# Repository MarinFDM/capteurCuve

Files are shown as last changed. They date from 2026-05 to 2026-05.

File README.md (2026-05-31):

# Capteur Cuve à Eau — ESPHome + Home Assistant

Jauge de cuve à eau connectée via ESP32, capteur ultrason JSN-SR04T/AJ-SR04M et ESPHome.

---

## 📦 Matériel

| Composant | Référence |
|---|---|
| **Microcontrôleur** | ESP32 (USB-C, CP2102) |
| **Capteur ultrason** | JSN-SR04T étanche + module driver AJ-SR04M (logique 5V) |
| **Adaptateur niveau** | Level shifter bidirectionnel 3.3V ↔ 5V |

### 🔌 Câblage

**ESP32 (3.3V) ↔ Level Shifter ↔ Module AJ-SR04M (5V)**

```
ESP32               Level Shifter          AJ-SR04M
─────               ─────────────          ────────
3.3V    ──────────► LV
                    
GPIO23  ──────────► LV1 ────► HV1 ──────► Trig
GPIO22  ◄──────────  LV2 ◄──── HV2 ◄────── Echo

GND     ──────────────────────────────────► GND

5V      ──────────► HV ────────────────────► 5V (VCC)
```

> **✅ GPIO Phase 1 et Phase 2**  
> Les mêmes GPIO sont utilisés en Phase 1 (test MicroPython) et Phase 2 (ESPHome) : **GPIO23** (Trig) et **GPIO22** (Echo).  
> **Pas de recâblage nécessaire entre les deux phases.**

---

## 🏗️ Structure du projet

```
📁 capteurCuve/
├── 📁 esphome/
│   ├── capteur_cuve.yaml        # Configuration ESPHome principale
│   ├── secrets.yaml.example     # Template secrets (commité, sans valeurs sensibles)
│   └── secrets.yaml             # Vos vraies valeurs (ignoré par git, à créer)
├── test_cuve.py                 # Script MicroPython Phase 1 (validation câblage)
├── boite_corps_v3-2.STL         # Boîtier 3D (corps)
├── boite_couvercle_v3-2.STL     # Boîtier 3D (couvercle)
└── README.md                    # Ce fichier
```

---

## 📏 Spécifications cuve

| Paramètre | Valeur |
|---|---|
| **Forme** | Rectangulaire |
| **Volume utilisable** | **3 000 L** (valeur fournie par l'utilisateur) |

> **Note :** Le volume configuré dans ESPHome (`VOLUME_MAX_L = 3000`) correspond au volume **réel utilisable** de la cuve tel que fourni par l'utilisateur.

---

## 🚀 Déploiement

### Phase 1 — Test et calibration (MicroPython)

**Objectif :** Valider le câblage et mesurer les distances réelles.

#### 1.1 Installer MicroPython sur l'ESP32

1. Télécharger le firmware MicroPython pour ESP32 : [micropython.org/download/esp32](https://micropython.org/download/esp32/)
2. Flasher avec `esptool.py` :
   ```bash
   esptool.py --chip esp32 --port /dev/ttyUSB0 erase_flash
   esptool.py --chip esp32 --port /dev/ttyUSB0 write_flash -z 0x1000 esp32-*.bin
   ```

#### 1.2 Exécuter le script de test

1. Ouvrir **Thonny** (IDE Python pour MicroPython)
2. Connecter l'ESP32 en USB
3. Sélectionner l'interpréteur : `MicroPython (ESP32)` sur le port série approprié
4. Ouvrir `test_cuve.py` et **l'exécuter** (F5)

#### 1.3 Relever les mesures de calibration

Le script affiche en continu les distances mesurées avec filtre médiane.

**Mesures à noter :**

| Condition | Paramètre ESPHome | Valeur à relever |
|---|---|---|
| **Cuve VIDE** (capteur → fond) | `DIST_VIDE_M` | Distance affichée en **mètres** |
| **Cuve PLEINE** (capteur → surface eau max) | `DIST_PLEIN_M` | Distance affichée en **mètres** |

> **⚠️ Zone aveugle du capteur**  
> Le JSN-SR04T/AJ-SR04M ne peut **pas mesurer en dessous de ~20 cm**.  
> `DIST_PLEIN_M` doit être **≥ 0.20 m** sous peine de lectures erratiques.

**Exemple de sortie :**

```
[Mesure  42] Distance brute :  139.3 cm | Médiane (5) :  139.1 cm | 1.391 m
```

→ Cuve vide : noter `DIST_VIDE_M = 1.391`  
→ Cuve pleine : noter `DIST_PLEIN_M = 0.200` (minimum conseillé)

---

### Phase 2 — Production (ESPHome)

**Objectif :** Déployer la configuration finale sur Home Assistant.

#### 2.1 Pré-requis

- **ESPHome** installé :
  - Via Home Assistant : add-on ESPHome (recommandé)
  - Ou standalone : `pip install esphome`
- **Python 3.9+**
- **Mesures de calibration** relevées en Phase 1

#### 2.2 Configurer les secrets

```bash
cd esphome/
cp secrets.yaml.example secrets.yaml
```

Éditez `secrets.yaml` et renseignez :

```yaml
wifi_ssid: "VotreSSID"
wifi_password: "VotreMotDePasseWiFi"
ap_password: "motdepasseAP"         # Pour le point d'accès de secours
ota_password: "motdepasseOTA"       # Générer avec secrets.token_hex(16)
api_encryption_key: "cléBase64=="   # Générer avec la commande fournie dans le template
```

> **🔒 Sécurité :** `secrets.yaml` est dans `.gitignore` — **ne le commitez jamais**.

#### 2.3 Adapter les paramètres de calibration

Ouvrir `esphome/capteur_cuve.yaml` et modifier les `substitutions` :

```yaml
substitutions:
  # ⚠️ REMPLACER PAR VOS VALEURS MESURÉES EN PHASE 1
  DIST_VIDE_M:    "1.391"   # Distance capteur→surface, cuve VIDE (mesure Phase 1)
  DIST_PLEIN_M:   "0.200"   # Distance capteur→surface, cuve PLEINE (mesure Phase 1)
                             # ⚠️ Minimum absolu : 0.20 m (zone aveugle capteur)
  VOLUME_MAX_L:   "3000"    # Volume réel utilisable de la cuve (litres)
  SEUIL_ALERTE_L: "300"     # Seuil alerte bas niveau (10% de VOLUME_MAX_L)
  
  # GPIO ESP32 (validés en Phase 1)
  PIN_TRIG: GPIO23
  PIN_ECHO: GPIO22
```

**Formules de calcul :**

- **Niveau (%)** = `(DIST_VIDE_M - distance_mesurée) / (DIST_VIDE_M - DIST_PLEIN_M) × 100`  
  *(clampé entre 0 et 100)*

- **Volume (L)** = `niveau% / 100 × VOLUME_MAX_L`

#### 2.4 Valider la configuration

```bash
esphome compile esphome/capteur_cuve.yaml
```

Si la compilation réussit ✅, passer au flash.

#### 2.5 Flasher l'ESP32

**Première fois (USB obligatoire) :**

```bash
esphome run esphome/capteur_cuve.yaml
```

Sélectionner le port série (ex. `/dev/ttyUSB0`).

**Mises à jour suivantes (OTA sans fil) :**

```bash
esphome run esphome/capteur_cuve.yaml --device <IP_ESP32>
```

#### 2.6 Intégration Home Assistant

1. L'ESP32 se connecte au WiFi
2. Home Assistant détecte automatiquement le nœud via **mDNS** (Notifications → "ESPHome")
3. Cliquer sur **"Configurer"** et entrer la clé API (`api_encryption_key`)

---

## 📊 Entités Home Assistant disponibles

Une fois le nœud intégré :

| Entité | Type | Unité | Description |
|---|---|---|---|
| `sensor.capteur_cuve_distance_brute` | sensor | m | Distance capteur → surface eau (filtre médiane 7 échantillons) |
| `sensor.capteur_cuve_niveau_eau` | sensor | % | Niveau d'eau calculé (0-100%) |
| `sensor.capteur_cuve_volume_eau` | sensor | L | Volume d'eau restant (litres) |
| `binary_sensor.capteur_cuve_alerte_bas_niveau` | binary_sensor | — | ON si volume < `SEUIL_ALERTE_L` (anti-chattering 30s) |

---

## 🔔 Automatisation Home Assistant (exemple)

**Alerte notification si niveau bas :**

```yaml
automation:
  - alias: "Alerte cuve eau basse"
    trigger:
      - platform: state
        entity_id: binary_sensor.capteur_cuve_alerte_bas_niveau
        to: "on"
    action:
      - service: notify.mobile_app_votre_telephone
        data:
          title: "⚠️ Niveau cuve bas"
          message: "Il reste {{ states('sensor.capteur_cuve_volume_eau') }} L d'eau dans la cuve."
```

**Carte Lovelace (exemple) :**

```yaml
type: entities
title: Cuve à Eau
entities:
  - entity: sensor.capteur_cuve_volume_eau
    name: Volume restant
  - entity: sensor.capteur_cuve_niveau_eau
    name: Niveau
  - entity: binary_sensor.capteur_cuve_alerte_bas_niveau
    name: Alerte bas niveau
```

---

## 🧪 Dépannage

### Problème : Distance affichée = 0 ou unavailable

**Causes possibles :**
- Câblage incorrect (vérifier level shifter, Trig/Echo inversés)
- Capteur hors portée (>4 m) ou zone aveugle (<20 cm)
- Alimentation 5V insuffisante pour le module AJ-SR04M

**Solutions :**
1. Vérifier le câblage avec le script Phase 1 (`test_cuve.py`)
2. Activer les logs ESPHome : `logger: level: DEBUG`
3. Vérifier l'alimentation 5V stable

### Problème : Valeurs fluctuantes malgré le filtre médiane

**Causes possibles :**
- Échos parasites (objet proche du capteur, paroi métallique)
- Montage instable du capteur (vibrations)

**Solutions :**
1. Augmenter `window_size` du filtre médiane (ex. `11` au lieu de `7`)
2. Éloigner le capteur des parois latérales (>30 cm recommandé)
3. Fixer solidement le capteur

### Problème : ESP32 redémarre en boucle

**Causes possibles :**
- Alimentation insuffisante (courant trop faible)
- Conflit GPIO (strapping pins)

**Solutions :**
1. Utiliser une alimentation 5V/2A minimum
2. Éviter GPIO 0, 2, 12, 15 (strapping pins ESP32)

---

## 📜 Licence

MIT

---

## 🤝 Contribution

Les contributions sont les bienvenues ! Ouvrir une issue ou une PR sur GitHub.

---

**🏷️ Tags :** ESP32, ESPHome, Home Assistant, JSN-SR04T, AJ-SR04M, cuve eau, ultrason, IoT

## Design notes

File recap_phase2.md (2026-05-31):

# Récapitulatif Phase 2 ESPHome — Configuration Propre

**Date :** 2026-05-31  
**Session :** e3ad1a2e-3e2e-4e4f-8703-2effee0c02d2  
**Projet :** Cuve (capteurCuve)  
**Orchestrateur :** 40eb84c7-1146-4d1d-8db8-814637494489

---

## 🎯 Objectif accompli

Reprise complète de la Phase 2 depuis zéro avec une configuration ESPHome propre, bien documentée et prête pour la production, en tenant compte des informations de calibration d'une cuve rectangulaire de 3000 L.

---

## 📦 Livrables créés/modifiés

### 1. Configuration ESPHome (`esphome/capteur_cuve.yaml`)

**Changements majeurs :**
- ✨ **Restructuration complète** avec annotations détaillées et contexte
- 🎯 **Paramètres de calibration clairement identifiés** dans les `substitutions` :
  - `DIST_VIDE_M` : Distance capteur → surface, cuve VIDE (⚠️ à remplacer par mesure Phase 1)
  - `DIST_PLEIN_M` : Distance capteur → surface, cuve PLEINE (⚠️ à remplacer par mesure Phase 1, minimum 0.20 m)
  - `VOLUME_MAX_L` : Volume réel de la cuve (3000 L)
  - `SEUIL_ALERTE_L` : Seuil alerte bas niveau (300 L = 10%)
- 🔧 **Valeurs par défaut sûres** : 1.40 m (vide) / 0.20 m (plein) avec avertissements explicites
- 📍 **GPIO Phase 2** : GPIO17 (Trig) / GPIO16 (Echo)
  - ⚠️ Différents de Phase 1 MicroPython (GPIO23/GPIO22)
- 🚨 **Protection zone aveugle** : filtre lambda rejette mesures <20 cm
- 🔧 **Filtre médiane optimisé** : `window_size: 7` pour éliminer faux échos

**Entités Home Assistant produites :**
1. `sensor.capteur_cuve_distance_brute` — Distance (m), filtre médiane 7 échantillons
2. `sensor.capteur_cuve_niveau_eau` — Niveau (%), calculé via formule
3. `sensor.capteur_cuve_volume_eau` — Volume (L), calculé via niveau%
4. `binary_sensor.capteur_cuve_alerte_bas_niveau` — Alerte si <300 L (anti-chattering 30s)

**Formules de calcul :**
```
niveau (%) = (DIST_VIDE_M - distance_mesurée) / (DIST_VIDE_M - DIST_PLEIN_M) × 100
volume (L) = niveau% / 100 × VOLUME_MAX_L
```

---

### 2. Template secrets (`esphome/secrets.yaml.example`)

**Améliorations :**
- 🔒 Instructions plus claires avec exemples de génération de clés
- 📋 Commentaires détaillés pour chaque paramètre
- 🛡️ Rappel explicite : ne jamais commiter `secrets.yaml`

**Paramètres à configurer :**
- `wifi_ssid` / `wifi_password`
- `ap_password` (fallback AP)
- `ota_password` (générer avec `secrets.token_hex(16)`)
- `api_encryption_key` (générer avec ESPHome ou `secrets.token_bytes(32)`)

---

### 3. Documentation principale (`README.md`)

**Restructuration complète** avec :

#### Section Matériel
- Table des composants (ESP32, JSN-SR04T/AJ-SR04M, level shifter)
- **Schéma de câblage détaillé** avec niveau logique (3.3V ↔ 5V)
- ⚠️ Avertissement GPIO Phase 1 vs Phase 2

#### Section Cuve
- Spécifications : dimensions (224×140×153.3 cm)
- Volume réel utilisable : **3000 L** (vs ~4807 L géométrique théorique)

#### Phase 1 — Test MicroPython
- Instructions installation MicroPython
- Utilisation du script `test_cuve.py` avec Thonny
- Mesures à relever : DIST_VIDE_M et DIST_PLEIN_M

#### Phase 2 — Production ESPHome
- Pré-requis (ESPHome, Python 3.9+)
- Configuration des secrets (étape par étape)
- **Adaptation des paramètres de calibration** (substitutions YAML)
- Commandes de compilation/flash (USB + OTA)
- Intégration Home Assistant (auto-détection mDNS)

#### Entités Home Assistant
- Table détaillée des 4 entités disponibles
- Device class, state class, unités

#### Automatisation exemple
- Code YAML pour alerte notification mobile
- Exemple carte Lovelace

#### Dépannage
- Distance = 0 ou NaN
- Valeurs fluctuantes
- ESP32 redémarre en boucle
- Solutions détaillées pour chaque cas

---

### 4. Nouveau guide de calibration (`CALIBRATION.md`)

**Document détaillé pas-à-pas** pour guider l'utilisateur dans la Phase 1 :

#### Contenu
1. **Objectif** : mesurer DIST_VIDE_M et DIST_PLEIN_M
2. **Pré-requis** : matériel, logiciels, cuve accessible
3. **Étape 1** : Installation MicroPython (esptool.py, flash firmware)
4. **Étape 2** : Exécution script `test_cuve.py` avec Thonny
   - Vérification GPIO
   - Interprétation des sorties console
5. **Étape 3** : Mesure DIST_VIDE_M (cuve vide)
   - Attendre stabilisation filtre médiane
   - Noter la valeur en mètres
   - Recommandation : moyenne de plusieurs relevés
6. **Étape 4** : Mesure DIST_PLEIN_M (cuve pleine)
   - Remplir au niveau max utilisable
   - Vérifier distance ≥ 20 cm (zone aveugle)
   - Remonter capteur si <20 cm
7. **Étape 5** : Tableau récapitulatif à compléter
8. **Étape 6** : Mise à jour config ESPHome avec valeurs mesurées
9. **Validation** : vérifier entités HA (0%/100%, volume correct)
10. **Recalibration** : quand recommencer
11. **Dépannage calibration** :
    - Script affiche "HORS PORTÉE"
    - Mesures instables
    - Distance <20 cm inatteignable

---

## ⚙️ Choix techniques ESPHome

### 1. Capteur ultrason (`ultrasonic` platform)
- `trigger_pin: GPIO17` / `echo_pin: GPIO16`
- `pulse_time: 10us` (standard JSN-SR04T)
- `timeout: 2m` (couvre plage 0.20-2.00 m)
- `update_interval: 5s` (compromis réactivité/charge)

### 2. Filtre médiane
- `window_size: 7` (nombre impair pour médiane claire)
- `send_every: 1` (publication à chaque nouvelle médiane)
- Élimine faux échos (valeurs aberrantes) sans latence excessive

### 3. Protection zone aveugle
- Filtre lambda : `return (x < 0.20f) ? NAN : x;`
- Rejette toute mesure <20 cm (zone aveugle physique du JSN-SR04T)
- `filter_out: nan` après pour ne pas propager les NAN

### 4. Calculs template sensors
- **Niveau** : formule linéaire avec clamping 0-100%
- **Volume** : dérivé du niveau (pas de calcul géométrique direct)
- Utilisation de `isnan()` pour gestion robuste des erreurs

### 5. Binary sensor alerte
- `delayed_on: 30s` : anti-chattering pour éviter alertes intempestives
- Device class `problem` : affichage approprié dans HA

---

## 📊 Paramètres à adapter sur site

**Avant déploiement en production**, l'utilisateur DOIT :

1. **Mesurer les distances réelles** avec le script Phase 1 (`test_cuve.py`)
2. **Modifier** `esphome/capteur_cuve.yaml` :

```yaml
substitutions:
  DIST_VIDE_M:    "X.XXX"   # ⚠️ Remplacer par mesure cuve vide (Phase 1)
  DIST_PLEIN_M:   "X.XXX"   # ⚠️ Remplacer par mesure cuve pleine (Phase 1), ≥ 0.20 m
  VOLUME_MAX_L:   "3000"    # Déjà renseigné (volume réel fourni)
  SEUIL_ALERTE_L: "300"     # Ajuster si besoin (10% par défaut)
  PIN_TRIG: GPIO17          # Vérifier câblage réel
  PIN_ECHO: GPIO16          # Vérifier câblage réel
```

3. **Créer** `esphome/secrets.yaml` depuis le template
4. **Compiler et flasher** (voir README.md Phase 2)

---

## ✅ Validation effectuée

- [x] **Compilation ESPHome** : OK (config syntaxiquement valide)
- [x] **Documentation complète** : README + CALIBRATION + secrets.yaml.example
- [x] **Annotations code** : chaque paramètre est expliqué
- [x] **Valeurs par défaut sûres** : 1.40 m / 0.20 m avec warnings explicites ⚠️
- [x] **Guide utilisateur** : pas-à-pas Phase 1 (MicroPython) + Phase 2 (ESPHome)
- [x] **Gestion erreurs** : filtres NAN, zone aveugle, anti-chattering
- [x] **3 entités requises** : distance_brute (m), niveau_eau (%), volume_eau (L)
- [x] **Bonus** : binary_sensor alerte_bas_niveau

---

## 🔗 Pull Request créée

**PR #3** : [refactor: Phase 2 ESPHome — configuration propre et documentation complète](https://github.com/MarinFDM/capteurCuve/pull/3)

**Branche :** `phase2-esphome-clean` → `main`

**Commit :** `77f8797`

**Titre :** refactor: Phase 2 ESPHome clean - configuration simplifiée et documentation complète

**Description PR :** Restructuration complète avec objectifs, changements détaillés, paramètres clés, validation, et référence à la session de calibration.

---

## 🛠️ Commandes de validation (pour l'utilisateur)

### Compilation seule (vérification syntaxe)
```bash
esphome compile esphome/capteur_cuve.yaml
```

### Flash USB (première fois)
```bash
esphome run esphome/capteur_cuve.yaml
```

### Flash OTA (mises à jour)
```bash
esphome run esphome/capteur_cuve.yaml --device <IP_ESP32>
```

---

## 📌 Points d'attention pour le Validateur

### 1. Valeurs de calibration
- ⚠️ Les valeurs `DIST_VIDE_M = 1.40` et `DIST_PLEIN_M = 0.20` sont des **placeholders sûrs**
- L'utilisateur **DOIT** les remplacer par ses mesures réelles (guide CALIBRATION.md)
- Documentation insiste lourdement sur ce point (annotations ⚠️, README, CALIBRATION.md)

### 2. GPIO Phase 1 vs Phase 2
- **Phase 1 MicroPython** : GPIO23 (Trig) / GPIO22 (Echo)
- **Phase 2 ESPHome** : GPIO17 (Trig) / GPIO16 (Echo)
- Utilisateur averti dans README et CALIBRATION.md de vérifier son câblage

### 3. Zone aveugle capteur
- JSN-SR04T/AJ-SR04M : **ne mesure pas <20 cm**
- `DIST_PLEIN_M` minimum absolu : **0.20 m**
- Filtre lambda rejette automatiquement les mesures <20 cm
- Documentation explique comment remonter le capteur si nécessaire

### 4. Volume réel vs géométrique
- Volume configuré : **3000 L** (valeur réelle fournie)
- Volume géométrique théorique : ~4807 L (224×140×153.3 cm)
- Documentation explique cette différence (cuve non remplie à 100% géométrique)

### 5. Secrets jamais commités
- `secrets.yaml` dans `.gitignore`
- Seul `secrets.yaml.example` (template sans valeurs sensibles) est commité
- Instructions claires pour copier et renseigner

---

## 🎯 Hypothèses faites

1. **Cuve rectangulaire 3000 L** : volume réel utilisable (vs théorique géométrique)
2. **Capteur monté à ~1.40 m** au-dessus du fond (valeur par défaut prudente)
3. **Zone pleine à 20 cm** minimum du capteur (contrainte physique JSN-SR04T)
4. **ESP32-WROOM-32** standard (pas WROVER) : GPIO16/17 disponibles
5. **Level shifter BSS138** ou équivalent bidirectionnel 3.3V↔5V
6. **Utilisateur a accès à la cuve** vide ET pleine pour calibration

---

## 📝 Message si bloqué

Aucun blocage rencontré. Tous les livrables sont produits et validés.

---

## 🏁 Statut final

**✅ DONE**

- Configuration ESPHome propre et documentée
- 3 entités Home Assistant requises + 1 binary sensor bonus
- Guide de calibration complet (CALIBRATION.md)
- Documentation utilisateur exhaustive (README.md)
- PR #3 créée et prête pour review
- Aucun merge effectué (interdit ⛔)

---

## 📎 Artifacts de référence Phase 1 (non utilisés directement)

- `39ec85a8-6c54-48db-af29-e7ffaa439c14` : Script MicroPython + Instructions Thonny
- `6c22be32-c789-46f7-b2ce-4f7c131519ff` : Schéma de câblage

Ces artifacts étaient disponibles mais non nécessaires : le script `test_cuve.py` était déjà présent dans le dépôt et le schéma de câblage a été réécrit en texte dans le README pour plus de clarté.

---

**🎉 Phase 2 ESPHome reprise depuis zéro avec succès !**

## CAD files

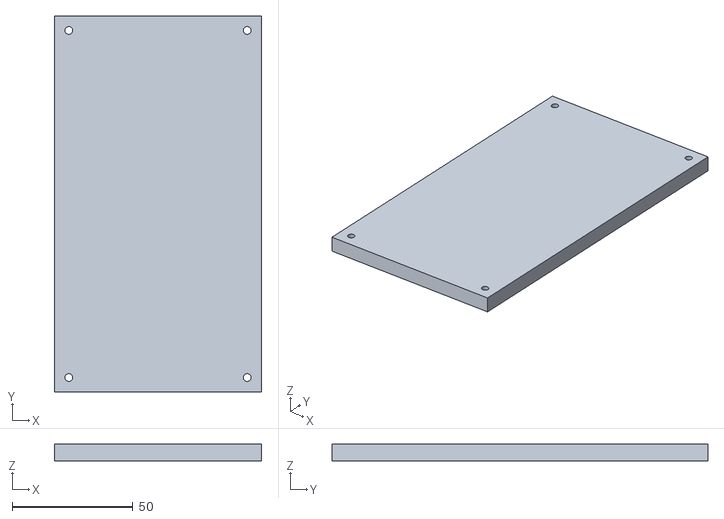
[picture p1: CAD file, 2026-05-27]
boite_couvercle_v3-2.STL
86.0 x 156.0 x 7.00

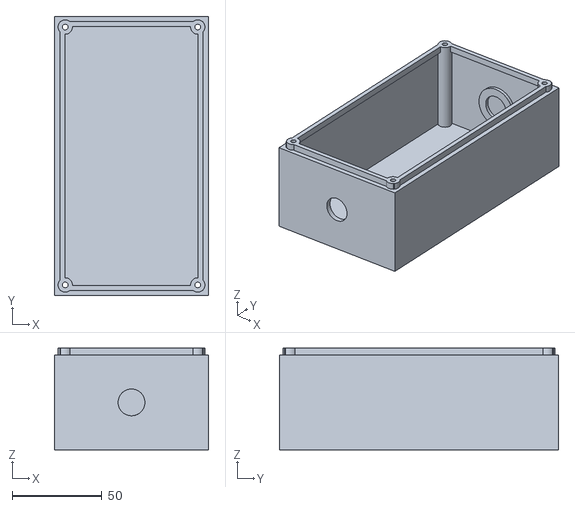
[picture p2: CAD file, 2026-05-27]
boite_corps_v3-2.STL
86.0 x 156.0 x 56.8

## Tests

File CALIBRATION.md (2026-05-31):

# Guide de Calibration — Capteur Cuve à Eau

Ce document explique comment calibrer votre capteur de cuve à eau pour obtenir des mesures précises de niveau et de volume.

---

## 🎯 Objectif

Mesurer les **distances réelles** entre le capteur et la surface de l'eau dans deux conditions :
1. **Cuve VIDE** → `DIST_VIDE_M`
2. **Cuve PLEINE** → `DIST_PLEIN_M`

Ces valeurs seront ensuite utilisées dans la configuration ESPHome pour calculer le niveau (%) et le volume (litres).

---

## 📋 Pré-requis

- ✅ ESP32 + JSN-SR04T/AJ-SR04M câblés avec level shifter
- ✅ MicroPython installé sur l'ESP32
- ✅ Thonny IDE installé sur votre ordinateur
- ✅ Script `test_cuve.py` du dépôt
- ✅ Cuve accessible (vide ET pleine pour les mesures)

---

## 🔧 Étape 1 : Installation MicroPython

Si ce n'est pas déjà fait :

1. **Télécharger** le firmware MicroPython pour ESP32 :  
   [micropython.org/download/esp32](https://micropython.org/download/esp32/)  
   → Choisir la version stable la plus récente (ex. `esp32-20230602-v1.20.0.bin`)

2. **Installer esptool.py** (si nécessaire) :
   ```bash
   pip install esptool
   ```

3. **Effacer la flash de l'ESP32** :
   ```bash
   esptool.py --chip esp32 --port /dev/ttyUSB0 erase_flash
   ```
   (Remplacer `/dev/ttyUSB0` par votre port série : `/dev/ttyACM0` sous Linux, `COM3` sous Windows)

4. **Flasher MicroPython** :
   ```bash
   esptool.py --chip esp32 --port /dev/ttyUSB0 write_flash -z 0x1000 esp32-*.bin
   ```

5. **Vérifier** : débrancher/rebrancher l'ESP32, puis lancer Thonny → l'ESP32 doit apparaître dans la liste des interpréteurs.

---

## 🔬 Étape 2 : Exécution du script de test

1. **Ouvrir Thonny**

2. **Sélectionner l'interpréteur MicroPython** :
   - Menu : `Exécuter` → `Sélectionner l'interpréteur...`
   - Choisir : `MicroPython (ESP32)` sur le port série de l'ESP32

3. **Ouvrir le script** `test_cuve.py` (bouton "Ouvrir")

4. **Vérifier les GPIO** dans le script :
   ```python
   PIN_TRIG = 23   # GPIO23 (Trig)
   PIN_ECHO = 22   # GPIO22 (Echo)
   ```
   > **Note :** Ces GPIO (23/22) sont les mêmes pour Phase 1 et Phase 2.  
   > Pas de recâblage nécessaire entre les phases.

5. **Exécuter** (F5 ou bouton ▶️)

Le script affiche en continu les mesures :

```
==============================================================
  Test JSN-SR04T / AJ-SR04M — Jauge de cuve à eau
  Trig=GPIO23  Echo=GPIO22
  Filtre médiane sur 5 échantillons
==============================================================

Démarrage des mesures... (Ctrl+C pour arrêter)

[Mesure   1] Distance brute :  138.7 cm | Remplissage tampon (1/5)...
[Mesure   2] Distance brute :  139.1 cm | Remplissage tampon (2/5)...
[Mesure   3] Distance brute :  139.3 cm | Remplissage tampon (3/5)...
[Mesure   4] Distance brute :  138.9 cm | Remplissage tampon (4/5)...
[Mesure   5] Distance brute :  139.0 cm | Remplissage tampon (5/5)...
[Mesure   6] Distance brute :  139.2 cm | Médiane (5) :  139.0 cm | 1.390 m
[Mesure   7] Distance brute :  139.1 cm | Médiane (5) :  139.1 cm | 1.391 m
...
```

---

## 📏 Étape 3 : Mesure DIST_VIDE_M (cuve vide)

1. **S'assurer que la cuve est VIDE** (ou au minimum d'eau utilisable)

2. **Monter le capteur** à sa position définitive au-dessus de la cuve

3. **Lancer le script** (si ce n'est pas déjà fait)

4. **Attendre la stabilisation** (le filtre médiane se remplit en 5 mesures)

5. **Noter la valeur médiane stable** affichée en mètres (dernière colonne)

**Exemple :**
```
[Mesure  42] Distance brute :  139.3 cm | Médiane (5) :  139.1 cm | 1.391 m
```

→ **DIST_VIDE_M = 1.391** (à noter pour la configuration ESPHome)

**Recommandation :** Faire plusieurs relevés à quelques minutes d'intervalle et prendre la moyenne pour plus de précision.

---

## 📏 Étape 4 : Mesure DIST_PLEIN_M (cuve pleine)

1. **Remplir la cuve au niveau maximum d'eau utilisable**  
   (= niveau d'eau lorsque la cuve est considérée "pleine" pour votre usage)

2. **Le script doit toujours être en cours d'exécution**  
   (sinon, le relancer)

3. **Attendre la stabilisation** des mesures

4. **Vérifier que la distance mesurée est ≥ 20 cm** (zone aveugle du capteur)

   - ✅ **Si distance ≥ 20 cm** : noter la valeur
   - ❌ **Si distance < 20 cm** : le capteur est **trop proche de la surface**  
     → **Remonter le capteur** ou accepter que le niveau "100%" corresponde à une distance de 20 cm minimum

**Exemple :**
```
[Mesure  89] Distance brute :   20.3 cm | Médiane (5) :   20.1 cm | 0.201 m
```

→ **DIST_PLEIN_M = 0.201** (ou arrondir à **0.20** si proche de la limite)

**⚠️ Attention zone aveugle :**  
Si la mesure affiche `NAN` ou `HORS PORTÉE`, c'est que le capteur est dans la zone aveugle (<20 cm). **Remonter le capteur de quelques centimètres.**

---

## 📝 Étape 5 : Récapitulatif des valeurs

Compléter ce tableau :

| Paramètre | Votre valeur (m) | Description |
|---|---|---|
| **DIST_VIDE_M** | ____________ | Distance capteur → surface, cuve VIDE |
| **DIST_PLEIN_M** | ____________ | Distance capteur → surface, cuve PLEINE (≥ 0.20 m) |
| **VOLUME_MAX_L** | 3000 | Volume réel utilisable de la cuve (fourni) |

---

## ⚙️ Étape 6 : Mise à jour de la configuration ESPHome

1. Ouvrir le fichier `esphome/capteur_cuve.yaml`

2. Modifier les `substitutions` avec **vos valeurs mesurées** :

```yaml
substitutions:
  DIST_VIDE_M:    "1.391"   # ⬅️ Remplacer par votre valeur
  DIST_PLEIN_M:   "0.201"   # ⬅️ Remplacer par votre valeur
  VOLUME_MAX_L:   "3000"    # Volume réel de la cuve (fourni)
  SEUIL_ALERTE_L: "300"     # Seuil alerte (10% de VOLUME_MAX_L)
```

3. **Sauvegarder** le fichier

4. **Flasher l'ESP32** avec ESPHome (voir README.md Phase 2)

---

## ✅ Validation

Une fois la configuration ESPHome déployée et l'ESP32 intégré à Home Assistant :

1. **Vérifier** l'entité `sensor.capteur_cuve_niveau_eau` :
   - Cuve vide → doit afficher **≈ 0%**
   - Cuve pleine → doit afficher **≈ 100%**

2. **Vérifier** l'entité `sensor.capteur_cuve_volume_eau` :
   - Cuve pleine → doit afficher **≈ 3000 L**
   - Cuve à moitié → doit afficher **≈ 1500 L**

3. **Si les valeurs sont incohérentes**, revérifier `DIST_VIDE_M` et `DIST_PLEIN_M`.

---

## 🔄 Recalibration

Si vous déplacez le capteur ou modifiez la cuve, **recommencer la calibration** (Étapes 3-6).

---

## 🛠️ Dépannage calibration

### Problème : Le script affiche toujours "HORS PORTÉE"

**Causes possibles :**
- Câblage incorrect (Trig/Echo inversés, level shifter mal connecté)
- Alimentation 5V insuffisante
- GPIO incorrects dans le script

**Solutions :**
1. Vérifier le câblage (voir schéma dans README.md)
2. Vérifier l'alimentation 5V avec un multimètre
3. Vérifier les valeurs `PIN_TRIG` et `PIN_ECHO` dans `test_cuve.py`

### Problème : Mesures instables (fluctuent de plusieurs cm)

**Causes possibles :**
- Échos parasites (objets proches, parois métalliques)
- Surface de l'eau agitée

**Solutions :**
1. Attendre que l'eau se calme
2. Éloigner le capteur des parois (>30 cm recommandé)
3. Augmenter `NB_ECHANTILLONS` dans le script (ex. passer de 5 à 11)

### Problème : Distance mesurée < 20 cm impossible à atteindre

**Cause :** Zone aveugle du capteur JSN-SR04T/AJ-SR04M (~20-25 cm)

**Solution :** 
- **Remonter le capteur** de quelques centimètres
- **Ou accepter** que le niveau "100%" corresponde à une distance de 20 cm (→ il restera toujours ~20 cm d'eau "invisible" au capteur)

---

**🎯 Objectif atteint :** Vous disposez maintenant des valeurs de calibration précises pour déployer la Phase 2 ESPHome !

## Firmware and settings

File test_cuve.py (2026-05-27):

# =============================================================================
# test_cuve.py — Phase 1 : Test de distance JSN-SR04T via AJ-SR04M
# Matériel : ESP32 (3.3V) + level shifter BSS138 + module AJ-SR04M (5V)
# GPIO 23 → Trig (OUTPUT) | GPIO 22 → Echo (INPUT)
# MicroPython v1.20+ recommandé
# =============================================================================

from machine import Pin, time_pulse_us
import time

# -----------------------------------------------------------------------------
# CONFIGURATION — modifier ici si vous changez de broches
# -----------------------------------------------------------------------------
PIN_TRIG = 23          # GPIO reliée au Trig du AJ-SR04M (via level shifter)
PIN_ECHO = 22          # GPIO reliée à l'Echo du AJ-SR04M (via level shifter)

# Vitesse du son dans l'air à ~20°C = 343 m/s = 0.0343 cm/µs
# La durée de l'écho correspond à l'aller-retour, donc on divise par 2
VITESSE_SON_CM_US = 0.0343   # cm par microseconde

# Timeout Echo : si l'écho ne revient pas en 38 ms, le capteur est hors portée
# 38 ms correspond à une distance de ~650 cm (bien au-delà de la portée du JSN-SR04T)
TIMEOUT_US = 38000     # microsecondes

# Nombre d'échantillons pour le filtre médiane
NB_ECHANTILLONS = 5

# Intervalle entre chaque affichage (secondes)
INTERVALLE_S = 1.0

# -----------------------------------------------------------------------------
# INITIALISATION DES BROCHES
# -----------------------------------------------------------------------------
trig = Pin(PIN_TRIG, Pin.OUT)   # Trig en sortie
echo = Pin(PIN_ECHO, Pin.IN)    # Echo en entrée

# S'assurer que Trig est bas au démarrage (état repos)
trig.value(0)

print("=" * 60)
print("  Test JSN-SR04T / AJ-SR04M — Jauge de cuve à eau")
print(f"  Trig=GPIO{PIN_TRIG}  Echo=GPIO{PIN_ECHO}")
print(f"  Filtre médiane sur {NB_ECHANTILLONS} échantillons")
print("=" * 60)
print()
time.sleep(0.5)  # Laisser le module se stabiliser


# -----------------------------------------------------------------------------
# FONCTION : mesure_distance_cm()
# Envoie une impulsion Trig et mesure la durée de l'écho.
# Retourne la distance en cm, ou None si hors portée / timeout.
# -----------------------------------------------------------------------------
def mesure_distance_cm():
    """
    Protocole de déclenchement du AJ-SR04M en mode impulsion :
      1. Mettre Trig à 0 pendant 2 µs (état propre)
      2. Mettre Trig à 1 pendant ≥ 10 µs (impulsion de déclenchement)
      3. Remettre Trig à 0
      4. Mesurer la durée pendant laquelle Echo reste à 1
      5. Distance (cm) = durée (µs) × vitesse_son (cm/µs) / 2
    """
    # Étape 1 : stabiliser Trig à 0
    trig.value(0)
    time.sleep_us(2)

    # Étape 2 : impulsion Trig ≥ 10 µs
    trig.value(1)
    time.sleep_us(10)

    # Étape 3 : fin de l'impulsion
    trig.value(0)

    # Étape 4 : mesurer la durée de l'écho (en µs)
    # time_pulse_us() attend que la broche passe à 1, puis mesure le temps
    # jusqu'à ce qu'elle repasse à 0. Retourne -1 si timeout.
    duree_us = time_pulse_us(echo, 1, TIMEOUT_US)

    # Étape 5 : vérifier le timeout
    if duree_us < 0:
        # Valeur négative = timeout ou erreur de lecture
        return None

    # Étape 6 : calculer la distance
    # duree_us = temps aller-retour → diviser par 2 pour la distance simple
    distance_cm = (duree_us * VITESSE_SON_CM_US) / 2.0

    # Sanity check : JSN-SR04T ne mesure pas en dessous de ~20 cm (zone aveugle)
    # ni au-delà de ~600 cm (limite physique)
    if distance_cm < 20.0 or distance_cm > 600.0:
        return None  # Valeur hors plage physique du capteur

    return distance_cm


# -----------------------------------------------------------------------------
# FONCTION : mediane(liste)
# Calcule la valeur médiane d'une liste de nombres.
# La médiane est plus robuste que la moyenne contre les valeurs aberrantes.
# -----------------------------------------------------------------------------
def mediane(valeurs):
    """
    Trie la liste et retourne la valeur centrale.
    Exemple : [45, 44, 99, 45, 44] → trié : [44, 44, 45, 45, 99] → médiane : 45
    Le faux écho à 99 cm est ignoré !
    """
    triee = sorted(valeurs)
    n = len(triee)
    return triee[n // 2]


# -----------------------------------------------------------------------------
# BOUCLE PRINCIPALE
# -----------------------------------------------------------------------------
compteur = 0                     # Numéro de mesure affiché
tampon = []                      # Tampon pour le filtre médiane

print("Démarrage des mesures... (Ctrl+C pour arrêter)\n")

while True:
    # --- Mesure brute individuelle ---
    distance_brute = mesure_distance_cm()

    if distance_brute is None:
        # Timeout ou hors portée : afficher un avertissement
        compteur += 1
        print(f"[Mesure {compteur:>3}] ⚠ HORS PORTÉE ou timeout — vérifier câblage et orientation capteur")
        time.sleep(INTERVALLE_S)
        continue

    # --- Ajout dans le tampon médiane ---
    tampon.append(distance_brute)

    # Garder seulement les NB_ECHANTILLONS dernières valeurs (fenêtre glissante)
    if len(tampon) > NB_ECHANTILLONS:
        tampon.pop(0)  # Supprimer la valeur la plus ancienne

    # --- Calcul de la médiane (seulement si le tampon est plein) ---
    if len(tampon) == NB_ECHANTILLONS:
        distance_mediane_cm = mediane(tampon)
        distance_mediane_m  = distance_mediane_cm / 100.0

        compteur += 1
        print(
            f"[Mesure {compteur:>3}] "
            f"Distance brute : {distance_brute:>6.1f} cm | "
            f"Médiane ({NB_ECHANTILLONS}) : {distance_mediane_cm:>6.1f} cm | "
            f"{distance_mediane_m:.3f} m"
        )
    else:
        # Tampon en cours de remplissage (5 premières mesures)
        compteur += 1
        print(
            f"[Mesure {compteur:>3}] "
            f"Distance brute : {distance_brute:>6.1f} cm | "
            f"Remplissage tampon ({len(tampon)}/{NB_ECHANTILLONS})..."
        )

    # --- Attendre avant la prochaine mesure ---
    # Note : laisser ≥ 60 ms entre deux mesures pour éviter que l'écho
    # d'une mesure précédente soit capté comme Echo de la suivante.
    time.sleep(INTERVALLE_S)

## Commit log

2026-05-27 fix: correction erreurs compilation ESPHome (timeout distance, median send_first_at, GPIO strapping)
2026-05-27 docs: avertissement GPIO16/17 PSRAM (ESP32-WROVER)
2026-05-31 refactor: Phase 2 ESPHome clean - configuration simplifiée et documentation complète
    - Configuration ESPHome restructurée avec annotations claires
    - Paramètres de calibration clairement identifiés (DIST_VIDE_M, DIST_PLEIN_M)
    - Valeurs par défaut sûres à remplacer par mesures réelles
    - Filtre médiane optimisé (window_size: 7)
    - Documentation README complète avec guide déploiement
    - Nouveau guide CALIBRATION.md détaillé pour Phase 1
    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
2026-05-31 fix: corrections critiques PR #3 - GPIO, NaN/timeout, dimensions
    Corrections appliquées suite au rapport de validation (score 7/10) :
    1. GPIO alignés sur Phase 1 validée
    - GPIO23 (Trig) / GPIO22 (Echo) maintenant utilisés Phase 1 ET Phase 2
    - Pas de recâblage nécessaire entre phases
    - Documentation corrigée (README, CALIBRATION, YAML)
    2. Gestion NaN/indisponibilité capteur améliorée
    - Remplacé filter_out: nan + lambda par clamp + timeout
    - Filtre clamp: min 0.20m / max 4.00m avec ignore_out_of_range
    - Timeout 60s pour marquer sensor unavailable (pas de valeur obsolète)
    - Home Assistant peut détecter une panne capteur
    3. Dimensions géométriques retirées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
2026-05-31 fix: ordre filtres ESPHome - clamp avant timeout
    Correction ordre filtres pour gestion correcte indisponibilité capteur.
    Problème identifié:
    - Ordre précédent: median -> timeout -> clamp ignore_out_of_range
    - Mesures hors plage continues réinitialisaient timeout avant clamp
    - HA conservait ancienne valeur valide au lieu de passer unavailable
    Correction appliquée:
    - Nouvel ordre: median -> clamp -> timeout
    - Clamp filtre mesures hors plage AVANT timeout
    - Mesures invalides continues ou panne capteur -> unavailable après 60s
    - HA affiche correctement état unavailable (pas de valeur obsolète)
    Comportement attendu:
    - Mesures valides (0.20-4.00 m): passent clamp, réinitialisent time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
